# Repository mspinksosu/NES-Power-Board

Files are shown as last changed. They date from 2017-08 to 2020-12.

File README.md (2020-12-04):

# NES-Power-Board
A PCB that will fit in place of the stock NES frontloader's RF module.
***
This PCB will replace the stock RF modulator box. It will have different connector options for outputting audio and video, as well as a breakout for the channel select switch.

I plan to support:
* composite video with mono audio
* composite video and "stereo" audio (standard 3 RCA TV connection)
* RGB + composite using a Retrofixes SNES style multiout connector.  (Requires existing RGB mod) This will be my version.
* RGB output directly to the Framemeister's 8-pin mini DIN connector. (Requires existing RGB mod)

The first two options require no modification to the chassis. All other versions will require some chassis modification, but it will minimal.

This PCB is designed specifically with Tim Worthington's NESRGB board in mind. The channel select switch will have a breakout so that it can be used as a palette selector switch.
***
# To-Do List for Rev 3
- [x] Flip ribbon connector. It will make the ribbon lay flatter (already did this for rev 2 doh!)
- [x] Check all through holes before sending to board house!
- [x] Change routing of RGB traces and audio traces completely
- [x] Separate video signals from audio signals to help avoid the static issue with the noise channel (may try 4 layer)
- [ ] Fix mounting hole location (may need to move J2)
- [x] C4 and C6 collide with heatsink of U1
- [x] Move components to bottom (working from the top is more difficult after installed)
- [x] Add extra surface mount ribbon connector, 1.27 mm pitch
- [ ] Test composite output (check if transistor bandwidth is sufficient)
- [ ] Band pass filter?

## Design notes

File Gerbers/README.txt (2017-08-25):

Project: NES Power PCB

Engineer: Matthew Spinks
Work Phone:
Evening Phone:

Address:

********************************************************************************

Unit = Inches
Format = 2:4
Filetype = 274X

Dimensions:
X = 2.738"
Y = 2.866"

Layer Count = 2
Thickness = 0.062"
Copper Wt. = 1 oz
Silkscreen: Both Sides

Files:

.DRL    Binary Drill File
.GBL    Bottom Copper
.GBO    Bottom Silkscreen
.GBS    Bottom Soldermask
.GD1    Drill Drawing
.GG1    Drill Guide
.GM1	Board Outline
.GTL    Top Copper
.GTO    Top Silkscreen
.GTS    Top Soldermask
.TXT    NC Drill File

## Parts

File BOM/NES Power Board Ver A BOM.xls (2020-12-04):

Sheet: Part List Report
 |  | Bill of Materials |  | NES Power Board Ver A.PrjPcb |  | Revision | 2000-02-05
 |  | Project: |  | NES Power Board Ver A.PrjPcb
 |  | Engineer:
 |  | Report Date: | 2020-12-03 | 20:12:00
 |  | Print Date: | 2020-12-03 | 20:12:32
# | Quantity | Value | Designator | Footprint | Description | Manufacturer 1 | Manufacturer Part Number 1 | Supplier 1 | Supplier Part Number 1
1 | 6 |  | Audio_L, Audio_R, GND, RCA_A, RCA_V, Video | WIREPAD-09-15 | Wire Pad, 1 Pin, Through Hole, Vertical
2 | 1 | 2200uF | C1 | TH CAP-12.5X25MM-A1K2 | CAP, ALUM, TH, 12.5x25mm, 2200uF, 25V, 20%, Pitch 5.0mm | Panasonic | ECA-1EHG222 | Mouser | 667-ECA-1EHG222
3 | 3 | 10nF | C2, C4, C5 | CAP 0805_N | CAP, CER, 0805, 10nF, 50V, X7R, 10%
4 | 1 | 100uF | C3 | TH CAP-6.3X11MM-A1K2 | CAP, ALUM, TH, 6.3x11mm, 100uF, 25V, 20%, Pitch 2.5mm | Panasonic | ECA-1EM101 | Mouser | 667-ECA-1EM101
5 | 1 | 0.1uF | C6 | CAP 0805_N | CAP, CER, 0805, 0.1uF, 50V, X7R, 10%
6 | 2 | 10uF | C7, C8 | CAP EIA-A (3216) A1K2 | CAP, TANT, 1206, 10uF, 16V, 10% | Kyocera AVX | TAJA106K016RNJ | Mouser | 581-TAJA106K016R
7 | 1 | DF206-ST | D1 | DFS4 | Full Wave Diode Bridge | Comchip | DF206ST-G | Mouser | 750-DF206ST-G
8 | 1 | PJ-037A | J1 | PWR-JCK-ALT (PJ-037A/B) | 2.1mm ID, DC Power Supply Connector, 2 Pin | CUI Devices | PJ-037A | Mouser | 490-PJ-037A
9 | 1 | RF Board Connector | J2 | RF Board Connector | Motherboard Connector to RF/Power Module
10 | 1 | 1.27mm Pitch | J3 | HDR1x11-15MM VERTL - L | Video and audio inputs for the RF Board Mod
11 | 1 | 1.27mm Pitch | J3A | SMD1x11-127MM | Video and audio inputs for the RF Board Mod
12 | 1 | Header 1x4 1.27mm | J4 | HDR1X4-15MM VERT - L | Header, 4 Pin, 1.5mm Pitch, Vertical
13 | 1 | MD-80SM | J5 | MINI-DIN-8-ALT (MD-80SM) | 8 Pin Mini DIN Connector, Shielded, Through Hole, Right Angle | CUI Devices | MD-80SM | Mouser | 490-MD-80SM
14 | 1 | Multiout | J6 | Multiout-2 | SNES Multiout Connector
15 | 2 | RCJ-042 | J7, J8 | RCA-JCK-1 (RCJ-042-ALT1) | RCA Phono Jack, Right Angle | CUI Devices | RCJ-042 | Mouser | 490-RCJ-042
16 | 1 | BC817 | Q1 | SOT23-3 | General Purpose Transistor, NPN, 3-Pin, B1E2C3 | ON Semiconductor | BC817-40LT1G | Mouser | 863-BC817-40LT1G
17 | 2 | 330 | R1, R3 | RES 0805_N | RES, SMD
18 | 1 | 5.6k | R2 | RES 0805_N | RES, SMD
19 | 1 | 560 | R4 | RES 0805_N | RES, SMD
20 | 1 | 75 | R5 | RES 0805_N | RES, SMD
21 | 2 | NA | RJA-EXT, RJV-EXT | RES 0805_N | RES, SMD
22 | 3 | 0 | RJA-INT, RJV-INT, RMONO | RES 0805_N | RES, SMD
23 | 1 | 470 | RSYNC | RES 0805_N | RES, SMD
24 | 1 | EG2319 | SW1 | SW-DP3T (EG2319) | Dual Pole, Three Throw | E-Switch | EG2319 | Mouser | 612-EG2319
25 | 1 | L7805ABD2T | U1 | D2PAK (TO-263) | Fixed 5V Regulator, 1.5A, D2PAK | STMicroelectronics | L7805ABD2T-TR | Mouser | 511-L7805ABD2T-TR
Notes

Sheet: Project Information
Project Full Path | C:\Users\maspin\Documents\GitHub\NES-Power-Board\NES Power Board Ver A.PrjPcb
Project Filename | NES Power Board Ver A.PrjPcb
Variant Name | None
Data-Source Filename | NES Power Board Ver A.PrjPcb
Data-Source Full Path | C:\Users\maspin\Documents\GitHub\NES-Power-Board\NES Power Board Ver A.PrjPcb
Title | NES Power Board Ver A.PrjPcb
Total Quantity | 38
Report Time | 20:12:00
Report Date | 2020-12-03
Report Date & Tine | 2020-12-03 20:12
Output Name | Bill of Materials
Output Type | BOM_PartType
Output Generator Name | BOM
Output Generator Description | Bill of Materials

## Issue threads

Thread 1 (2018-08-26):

Cannot Import Power PCB.PcbDoc in Altium CircuitStudio File Corrupt

R5D4ca, 2018-08-26:
Hello,
I'm interested in the project and new to PCB design in general, I wanted to try and open the design files and poke around but it looks like your files are from Altium Designer (based on the file extension and embedded metadata) and I only have a trial version of CircuitStudio available to me.  When I tried to import the necessary files the schematic file came in no problem but the PCB file says it is corrupt.

So far as I can tell so long as the PCB file from Altium Designer is version 5.0 or 6.0 this import should work.
Was wondering if you might know how to address this please?

mspinksosu, 2018-08-26:
Not sure about this one. I'll have to look into it tomorrow. I've left my
laptop at work which has Altium on it. Did you mean to say Altium 15.0 or
16.0? I know Altium has some built in exporters now, but I don't think they
go back that far.

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

R5D4ca, 2018-08-26:
Thanks for the response, you know strangely enough it only offers Altium PCB 5.0 and 6.0 as an option for importing.

Googling about this issue brought up a youtube video [https://www.youtube.com/watch?v=YAWBsShCId4](url) where the guy essentially says Altium seems to be purposely limiting the import abilities to older versions to remove overlap between the two products (great - love when companies do that).  Fortunately he also says you can simply re-save the PCB file to a version 5.0 from within Altium Designer to get around this issue and that the new file should just work.

R5D4ca, 2019-01-12:
I thought I had mentioned it here but I guess not; the reason I was trying to load the files is because when I go to OSH Park to try and print the PCB it gave me an error with the drill file but since you've upload the new version I've tried it again and now it gives me errors with the copper layer, mask layer, outline file, and drill file lol

Any chance for assistance please?  :)

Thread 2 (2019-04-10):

Incorrect Part Number

bikedude880, 2019-04-10:
https://github.com/mspinksosu/NES-Power-Board/blob/e8f472a10f18f6f2d27275b2264882e76d683c5a/NES%20Power%20Board.Dat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

This pad calls for a SPDT slide switch. This should really be a DP3T switch given the landing for the part.

Which manufacturer part is this now? Current one is SPDT and will never fit.

bikedude880, 2019-04-10:
Following part seems to be a fit for the landing:

E-Switch EG2319

https://www.mouser.com/ProductDetail/E-Switch/EG2319?qs=f57gQzlyLirXT6sCFZHxDA%3D%3D

bikedude880, 2019-04-11:
Please also note that R1, R2 and R3 are also missing.

radabass, 2019-07-10:
Hi @bikedude880, the part is the EG2322

https://eu.mouser.com/ProductDetail/E-Switch/EG2322?qs=sGAEpiMZZMvGqlubrpfvZYMIW9vnpXDI

As you can see in the commit https://github.com/mspinksosu/NES-Power-Board/commit/bfbaa42909d37d6ba6428c98cd207ca6bb8a1903

mspinksosu, 2020-12-04:
BOM has been added for version 2-5-0 (version A).

Closed 2020-12-04.

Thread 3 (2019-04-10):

Not all connectors plated through

bikedude880, 2019-04-10:
Not plated:
J2 - Motherboard Connector
J4 - Switch Breakout
J6 - Retrofixes MultiOut Connector

icestormmusic, 2019-05-20:
@bikedude880 - I am looking at doing this upgrade as well.  Did you have to modify the board before getting it printed to correct this issue?  I'm not much of a circuit guy, but I can solder.

bikedude880, 2019-06-01:
@icestormmusic I only noticed after printing the board, so yes. For J2, I took 24 gauge stranded wire, splayed it out and soldered it one side, pulled it through and soldered the other. SW1 can have patch wire run from the bottom of connector, non-issue.
J6 is where things get interesting. All the signal connections are made in the top of the board underneath the physical connector. This needs to be fixed in the Gerber files.

Also note that there is an issue using the stock composite circuit out from J2. The circuit is missing a band-pass filter after R5 which requires a 3.3mH inductor and capacitor. Without this the only thing this board is good for currently is power :(

OOF1337, 2020-12-01:
I know this is an old thread but are there any other issues with it? I'm thinking of hiring someone to fix the issues if there are any.

mspinksosu, 2020-12-01:
There are issues with it. It's noisy. When I originally made it, I had designed it in such a way that it could be made at home if desired. That means that I intentionally tried to use a small number of vias. Some of the traces snake around pins on the RGB connector. It's now so cheap to get a board from a fab house that this no longer necessary. I'll remake it someday with a 4 layer board when I'm not busy and COVID-19 is over with

OOF1337, 2020-12-01:
Hi! While I have you here this is about the revision 2.0A and B correct? How identical are they from one another? From what I can tell version B doesn't support RGB while A does but other than those differences, as the layout and schematics model currently stand, would there be any other advantages in going with one or the other?

bigboy061293, 2020-12-02:
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

I guess the non plated issues were fixed in the lasted revision. We just need to add the BPF, right?

OOF1337, 2020-12-02:
@bigboy061293 Did you check the 2.0 file A or B directly to see if the plated issues were fixed? If so, do you know where to put the Vias or Band-pass filter? can you also tell me what "J6 is where things get interesting. All the signal connections are made in the top of the board underneath the physical connector." means? Sorry for being nosey XD.

mspinksosu, 2020-12-02:
2.0 A and B should have fixed the through hole plating, but I'll have to check when I get home. Currently working at night due to covidiots at work. 1.0 was my first time using Altium and I goofed. I've also had some issues syncing Github between home computer and work computer. Next time, I'll just get a portable drive.

mspinksosu, 2020-12-02:
I

> Hi! While I have you here this is about the revision 2.0A and B correct? How identical are they from one another? From what I can tell version B doesn't support RGB while A does but other than those differences, as the layout and schematics model currently stand, would there be any other advantages in going with one or the other? Thank you for your previous response by the way, wasn't expecting that!

I originally tried to make one board with two connectors. I literally just tried to place the two footprints on top of each other, but they way the holes are I had to push the mini din connector back into the housing and I didn't like that. So on the next revision, I made two different versions. I believe every thing else is the same. But again, I'll have to check

OOF1337, 2020-12-02:
@mspinksosu Once again, thank you for the reply.

mspinksosu, 2020-12-02:
> Also note that there is an issue using the stock composite circuit out from J2. The circuit is missing a band-pass filter after R5 which requires a 3.3mH inductor and capacitor. Without this the only thing this board is good for currently is power :(

I did find a somewhat crudely drawn, reverse engineered schematic for the RF box and I saw the filter. I did a limited amount of research into the composite output. I mostly looked at mods that were applied to the NES top loader to add composite output. It would appear that most top loader mods just consist of a single transistors and a few resistors and caps. I assumed that the filter was there to limit noise from the RF modulator literally inches away. And since I am removing the RF modulator entirely, I just assume that I don't need it. I have not had a chance to test it

bigboy061293, 2020-12-02:
> > Also note that there is an issue using the stock composite circuit out from J2. The circuit is missing a band-pass filter after R5 which requires a 3.3mH inductor and capacitor. Without this the only thing this board is good for currently is power :(
>
> I did find a somewhat crudely drawn, reverse engineered schematic for the RF box and I do remember seeing a filter in there. (I can't remember exactly what values) I did a limited amount of research into the composite output. I mostly looked at mods that were applied to the NES top loader to add composite output. It would appear that most top loader mods just consist of a single transistors and a few resistors and caps. I assumed that the filter was there to limit noise from the RF modulator literally inches away. And since I am removing the RF modulator entirely, I just assume that I don't need it. I have not had a chance to test it

I guess we need to look at the frequency characteristic of Video Out (Which I have not researched yet) and could replicated the BPF.

mspinksosu, 2020-12-04:
> I know this is an old thread but are there any other issues with it? I'm thinking of hiring someone to fix the issues if there are any.

I took a little, much needed time off and did up a version 2-5-0 for you. All plated holes are fixed and I re-routed a majority of the traces to try to improve noise issues. I'm only doing the version with the mini-din connector for now (version A). I'll do the other one after I've tested the first. I don't want to waste money on two PCB's unless I know it's going to work.

Unfortunately, I'm not sure when I'll be able to actually test it out. I've got a lot of mandatory home renovation going on (2020 is literally the worst). But I can order 10 PCB's and if you give me a few bucks, I can ship you one flat rate.

Once everything is done, I'll update Hackaday again.

OOF1337, 2020-12-06:
@mspinksosu While I appreciate the offer there are things I have to wait on first before I could definitively say yes or no. I'll let you know when I can give you an answer. I do appreciate your work on this though! My goal was to contribute towards the goal of making sure that there are open source solutions for the NES ever since the Opentendo was created earlier this year and I thought that aside from a 3d printed case model and controller ports that the RF/power adapter was the last piece in the puzzle for a open source NES.

SteelBattalion, 2021-04-24:
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

I know this is an old thread but do you still have any of those extra boards?

mspinksosu, 2021-04-24:
> I know this is an old thread but do you still have any of those extra boards?

Hi. So I actually left my old job and got a new one a few states away. Things have been pretty crazy. I'm still in the process of selling and buying a house, so everything I own is in storage right now. Not sure when I'll be able to get them. My goal is to move into a new house by the end of this summer.

zombie343, 2022-03-13:
Hi @mspinksosu, I hope your move went well. 👍  I've been following this project because I'd like to replace the RF box on my front-loader and mix the stereo output. :)

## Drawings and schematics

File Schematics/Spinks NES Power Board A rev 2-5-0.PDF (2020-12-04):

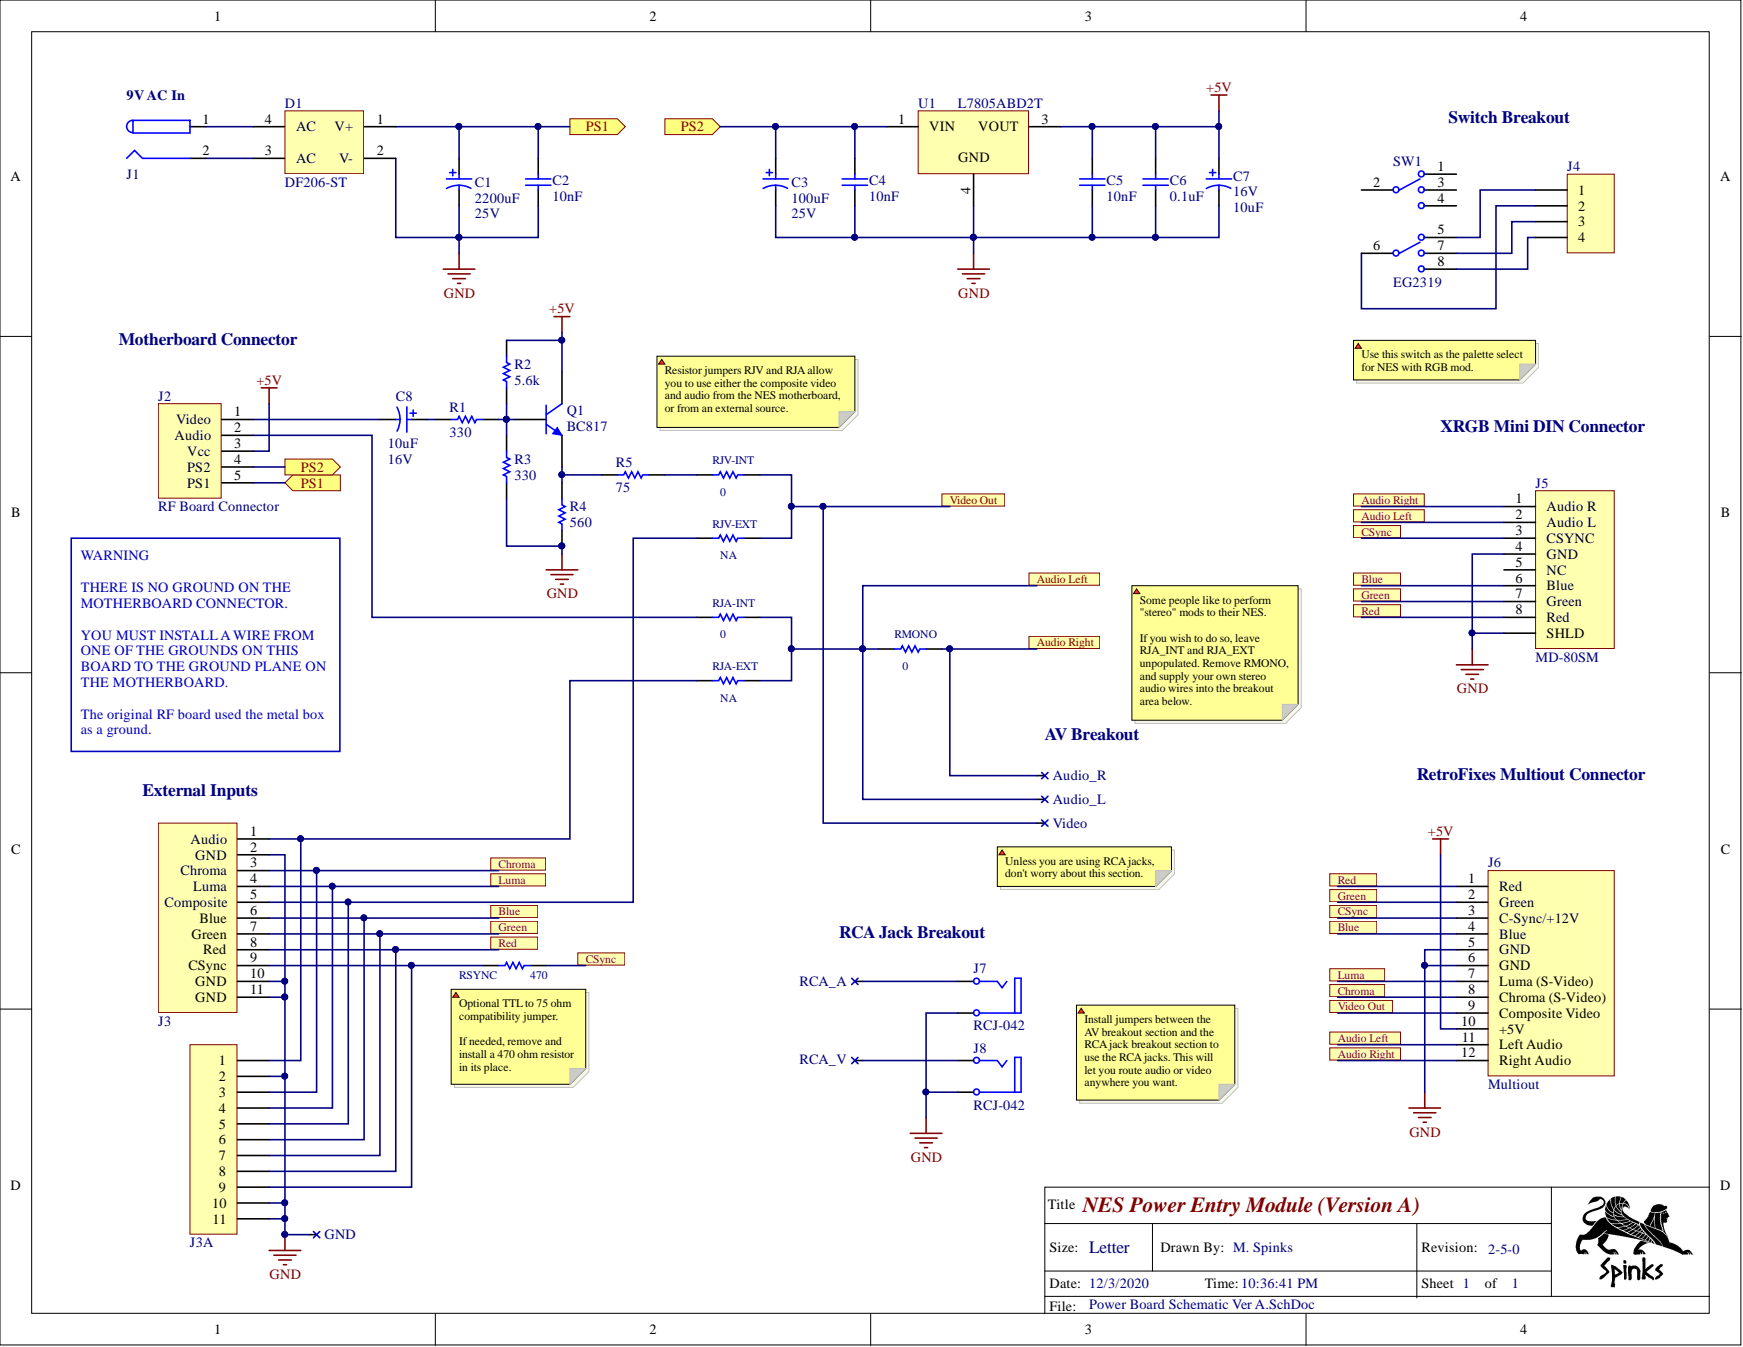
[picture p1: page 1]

Use this switch as the palette select
for NES with RGB mod.

Resistor jumpers RJV and RJAallow
you to use either the composite video
and audio from the NES motherboard,
or from an external source.

XRGB Mini DIN Connector

Audio Left | Audio L 2
CSync | CSYNC 3

GND 4
NC 5

THERE IS NO GROUND ON THE
MOTHERBOARD CONNECTOR.

Green | | Green 7
Red | | Red 8

Some people like to perform
"stereo" mods to their NES.

YOU MUST INSTALL A WIRE FROM
ONE OF THE GROUNDS ON THIS
BOARD TO THE GROUND PLANE ON
THE MOTHERBOARD.

If you wish to do so, leave
RJA_INT and RJA_EXT
unpopulated. Remove RMONO,
and supply your own stereo
audio wires into the breakout
area below.

The original RF board used the metal box
as a ground.

Unless you are using RCAjacks,
don't worry about this section.

Chroma | | Chroma (S-Video) 8
Video Out | | Composite Video 9

Optional TTL to 75 ohm
compatibility jumper.

Install jumpers between the
AV breakout section and the
RCAjack breakout section to
use the RCAjacks. This will
let you route audio or video
anywhere you want.

If needed, remove and
install a 470 ohm resistor
in its place.

NES Power Entry Module (Version A) Title

Size: Letter | Drawn By: M. Spinks | Revision: 2-5-0

Date: 12/3/2020 Time: 10:36:41 PM | | Sheet 1 of 1

Power Board Schematic Ver A.SchDoc
File:

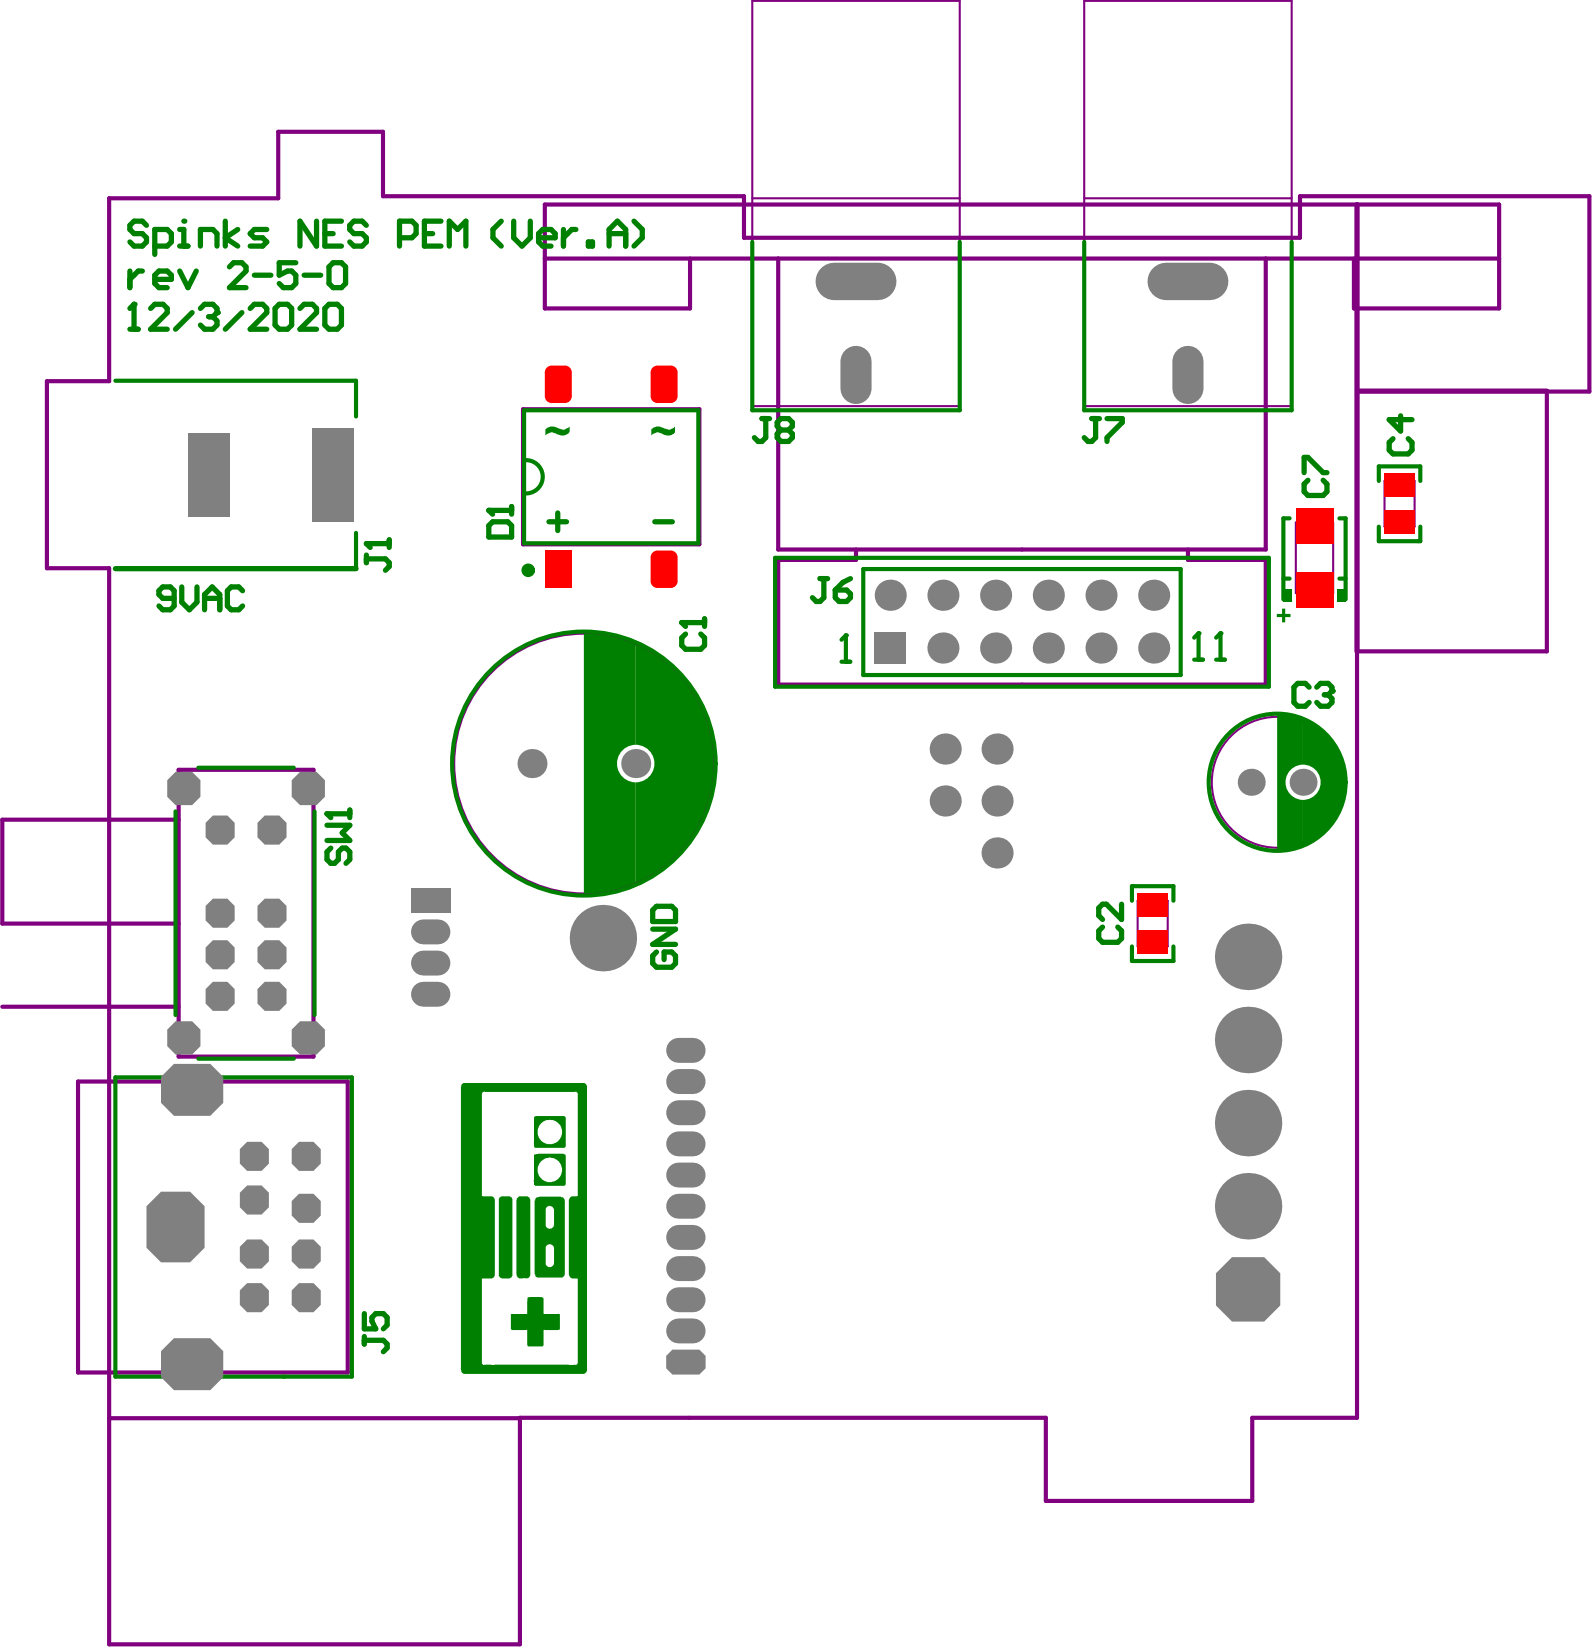
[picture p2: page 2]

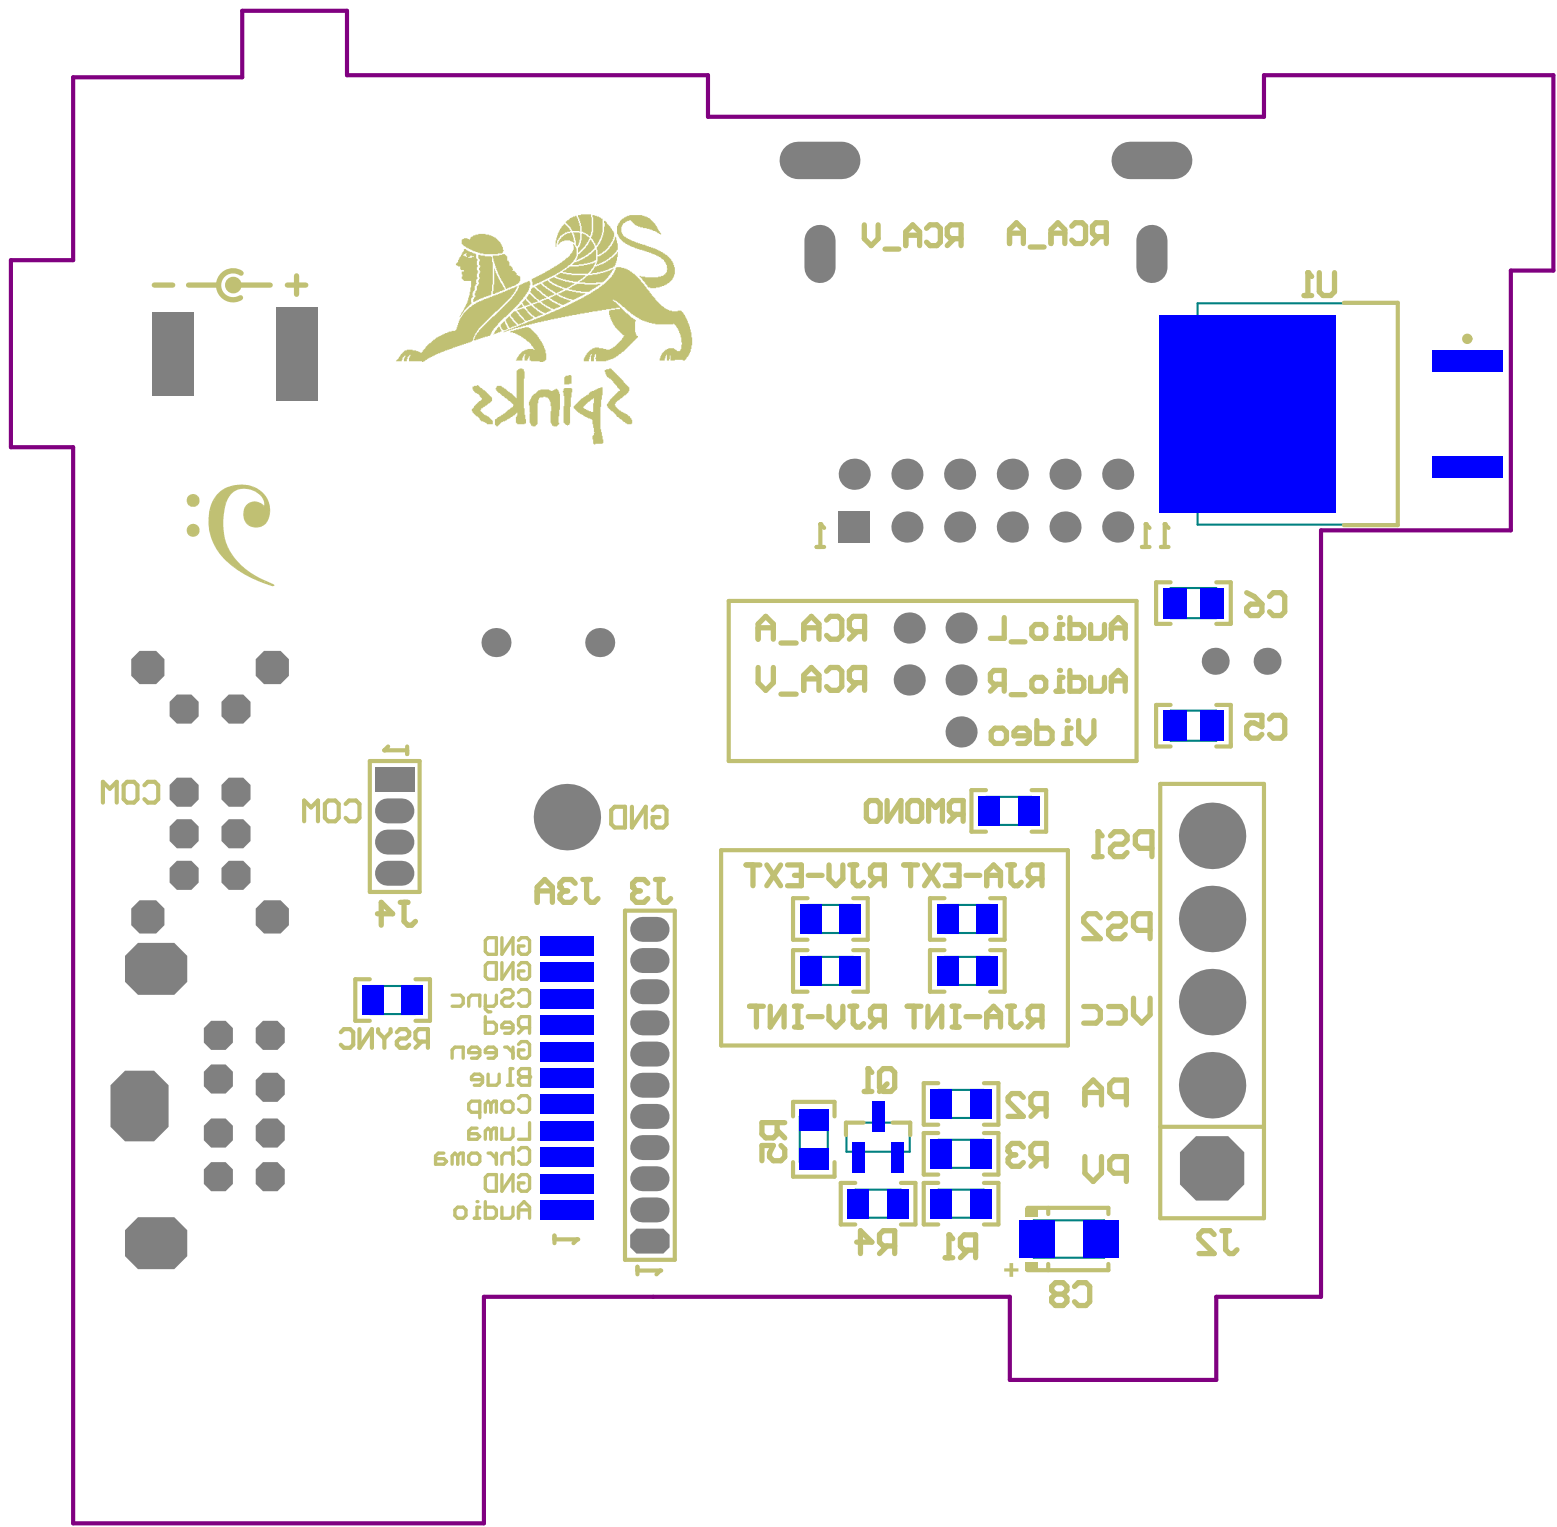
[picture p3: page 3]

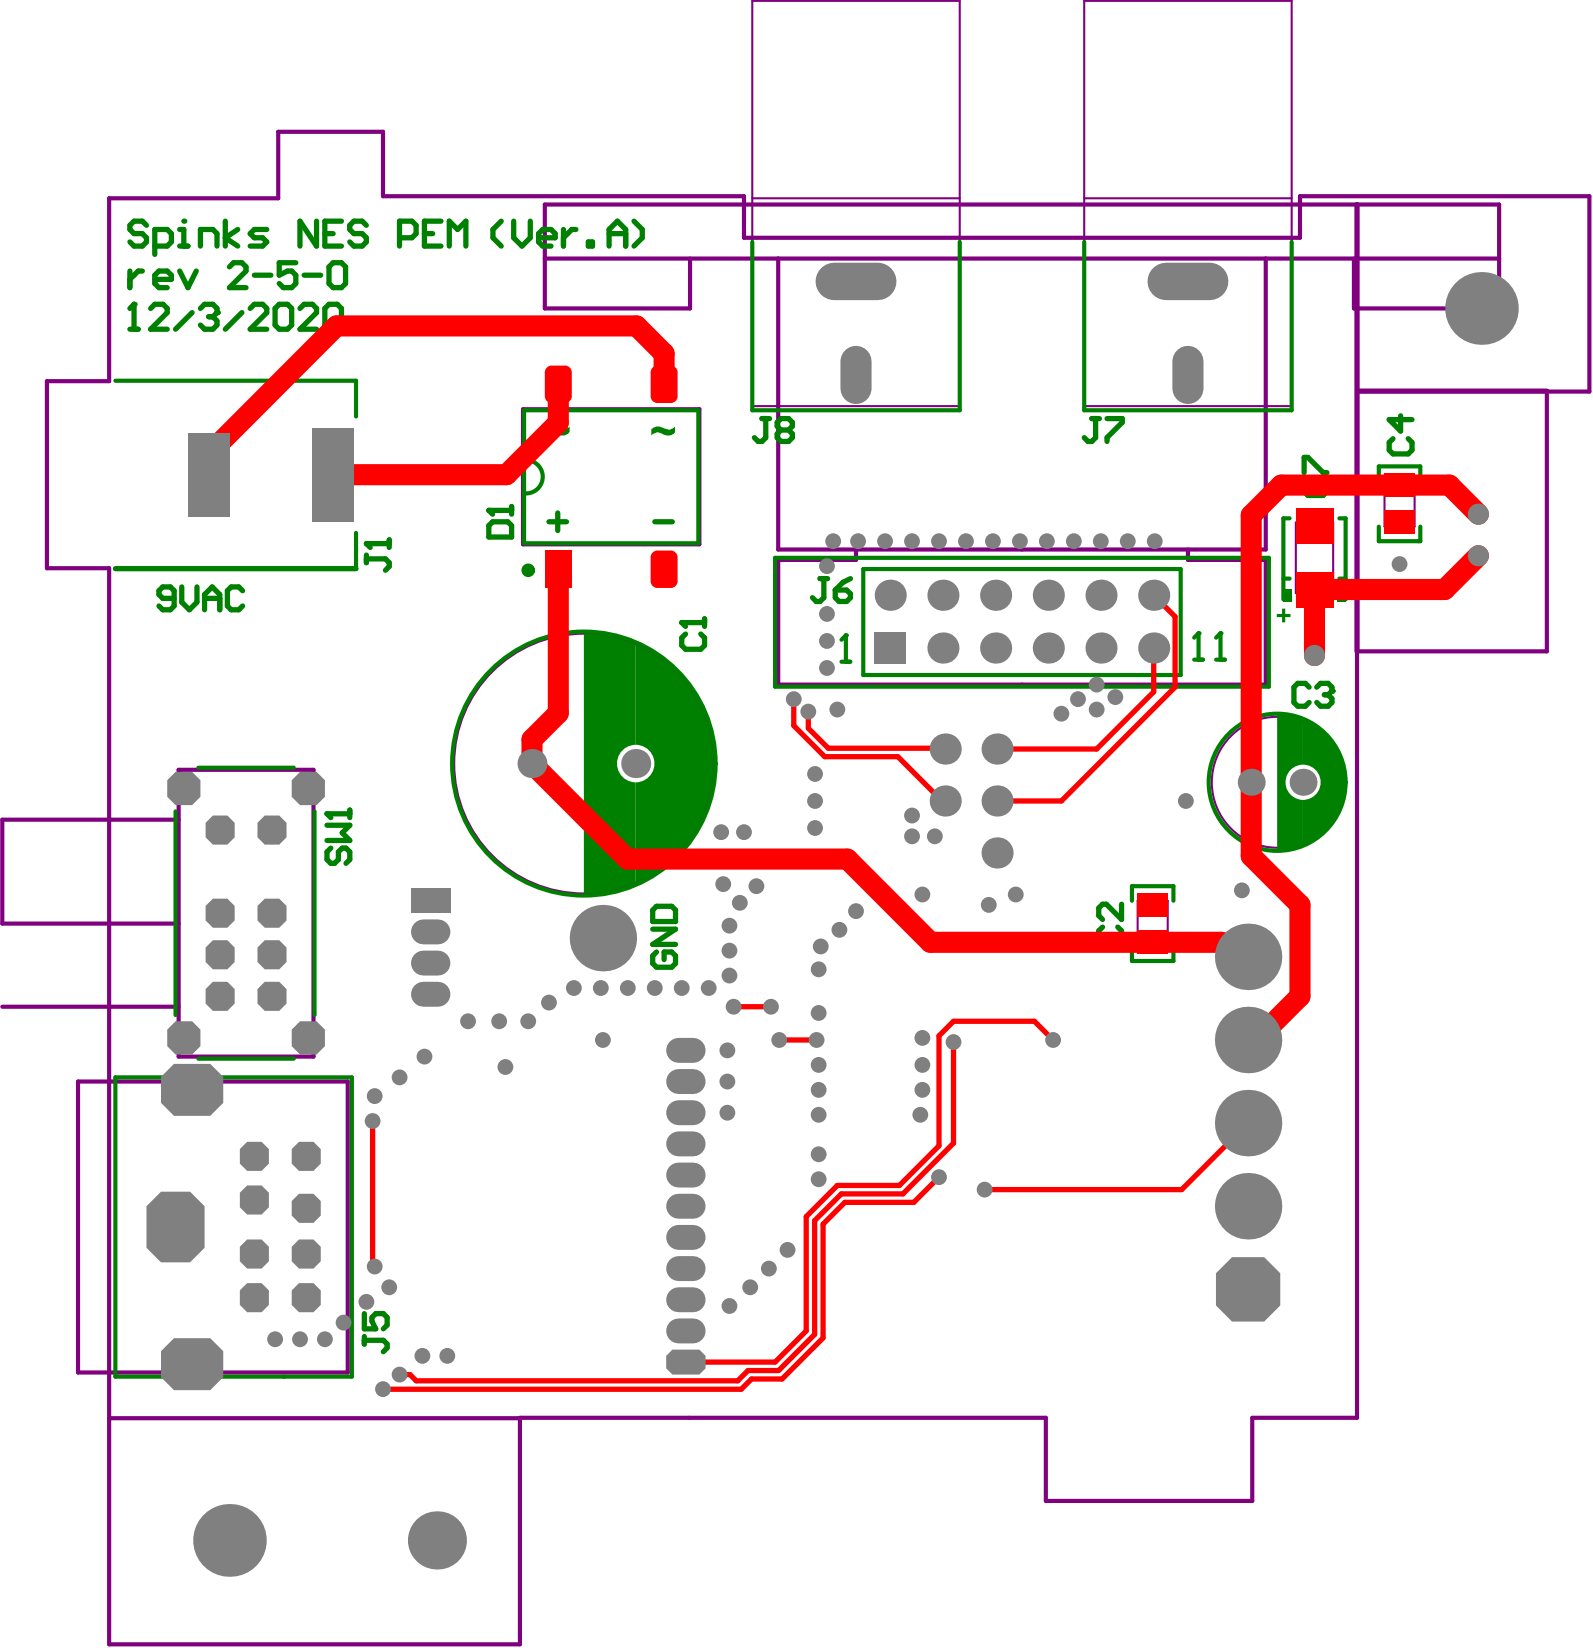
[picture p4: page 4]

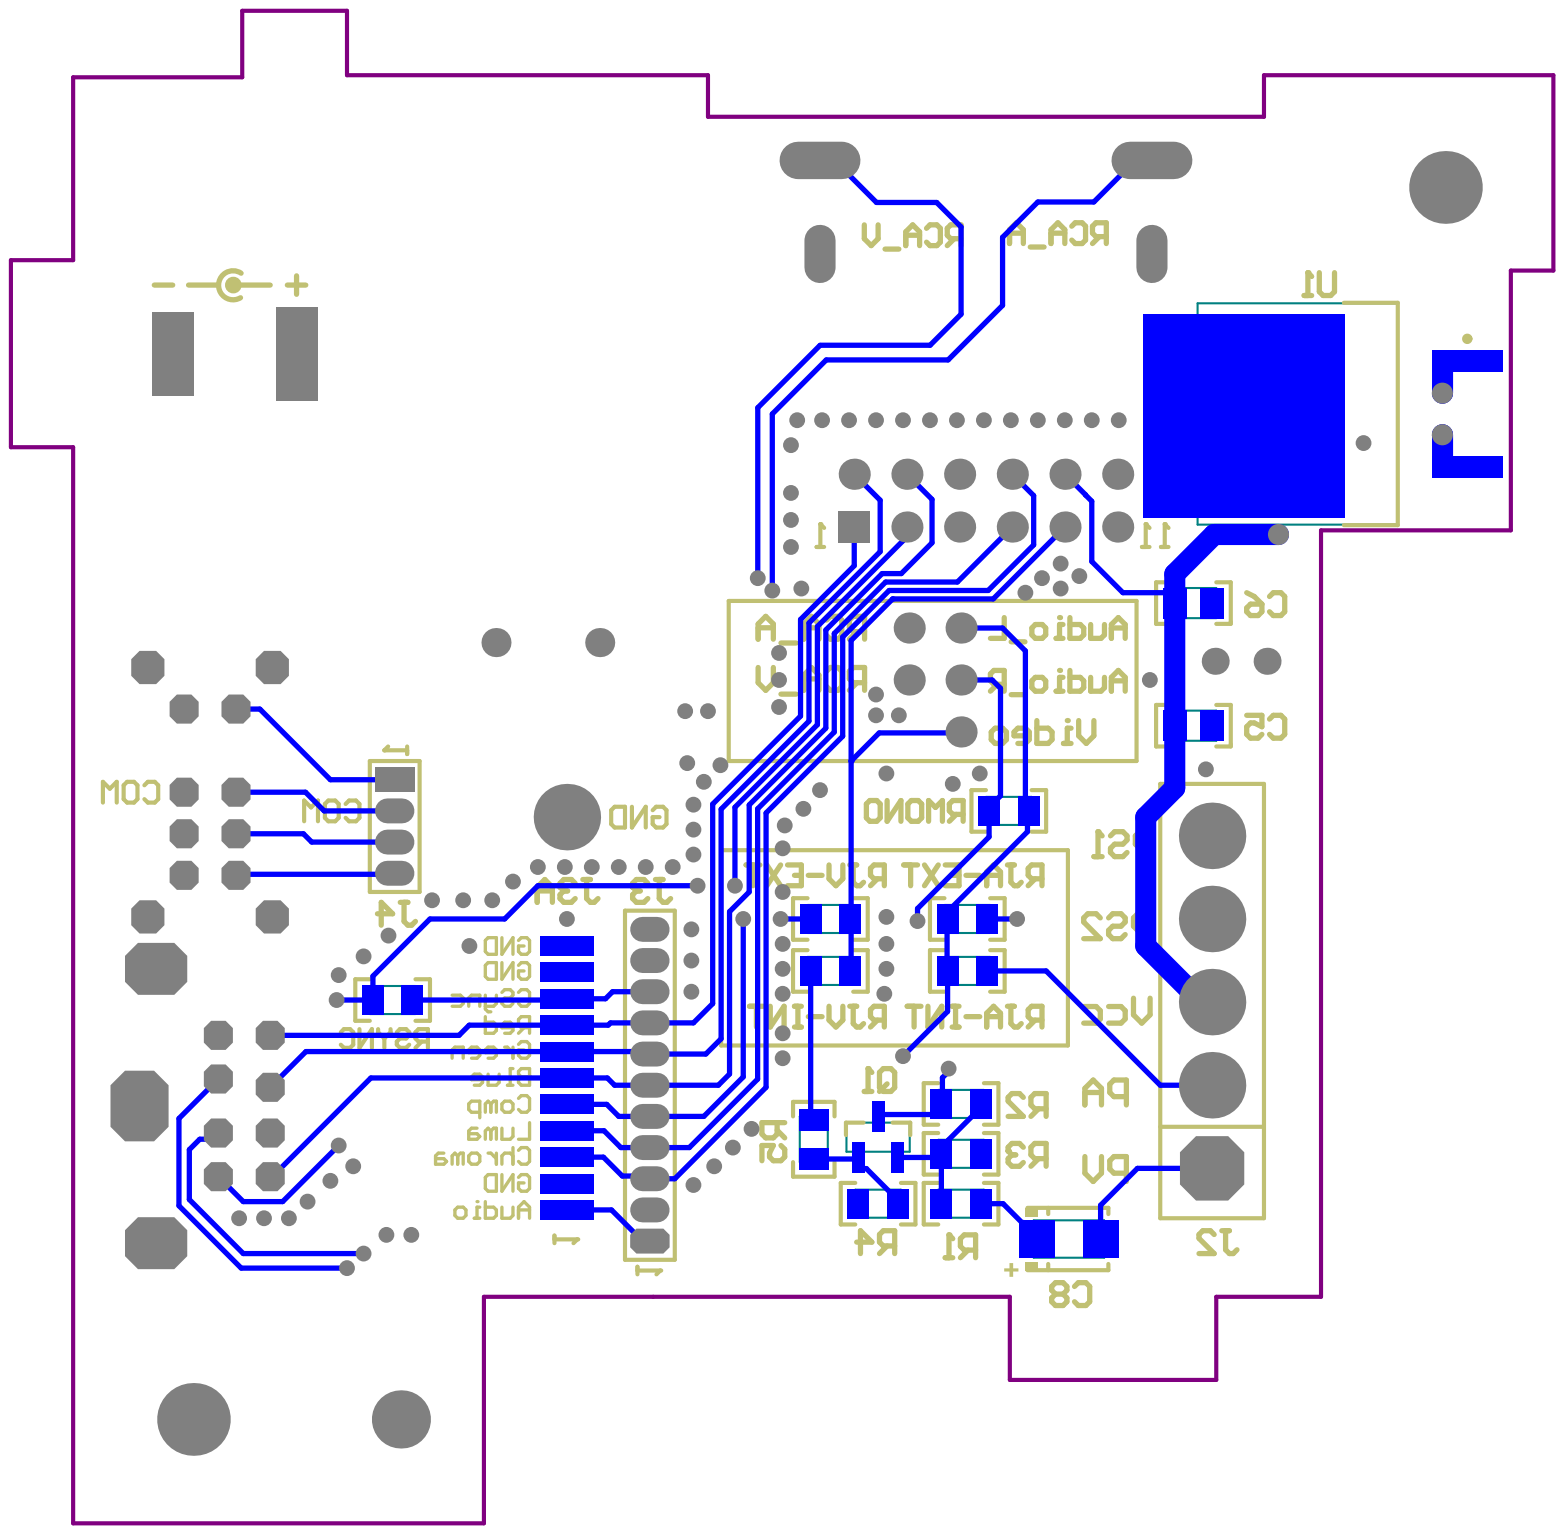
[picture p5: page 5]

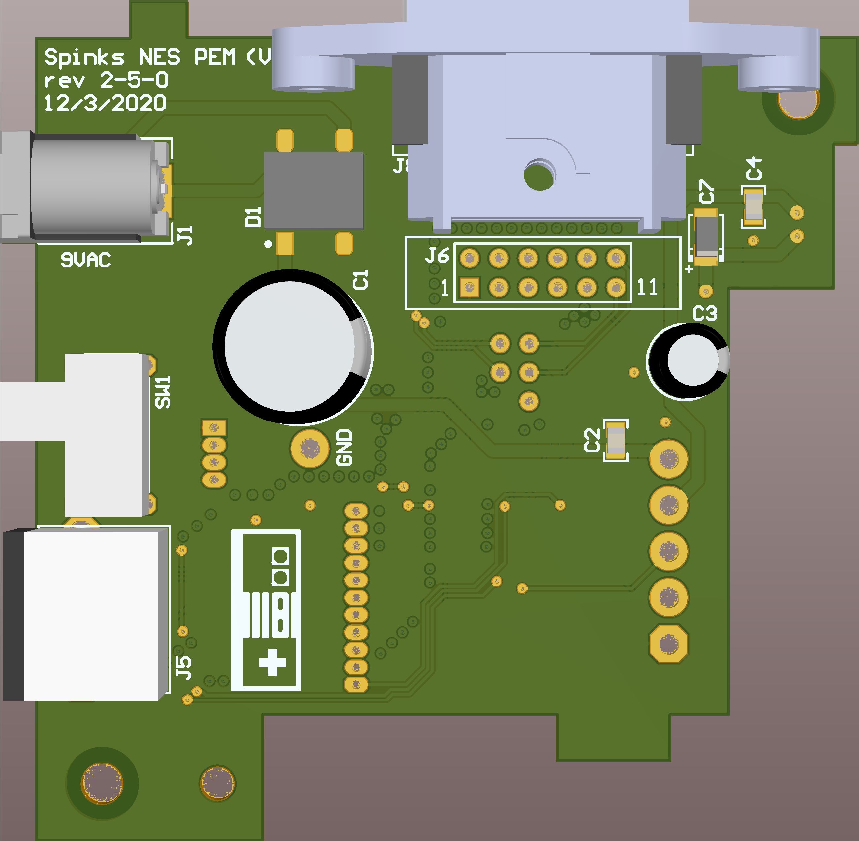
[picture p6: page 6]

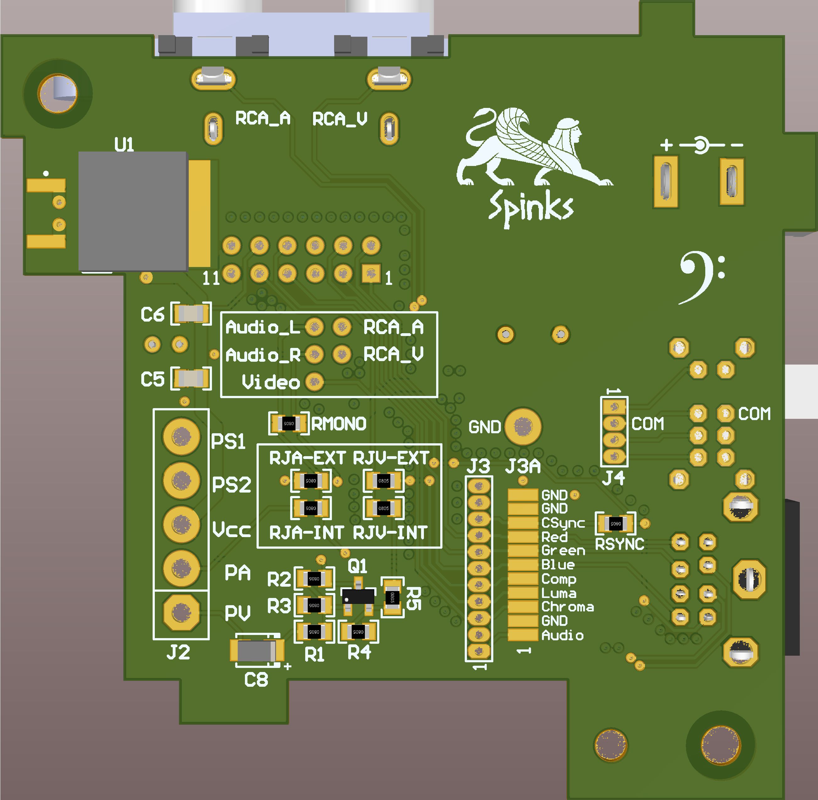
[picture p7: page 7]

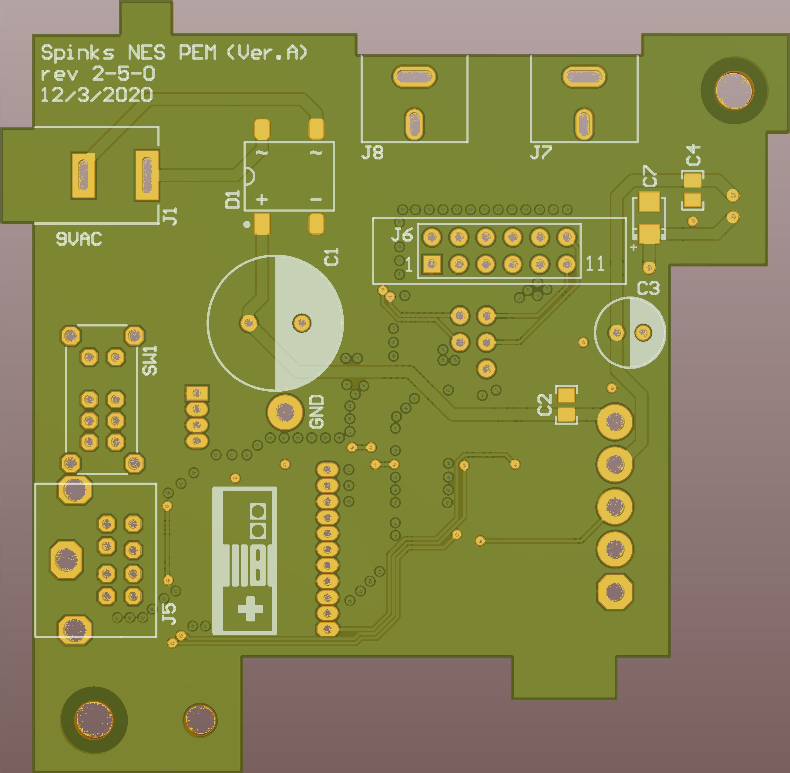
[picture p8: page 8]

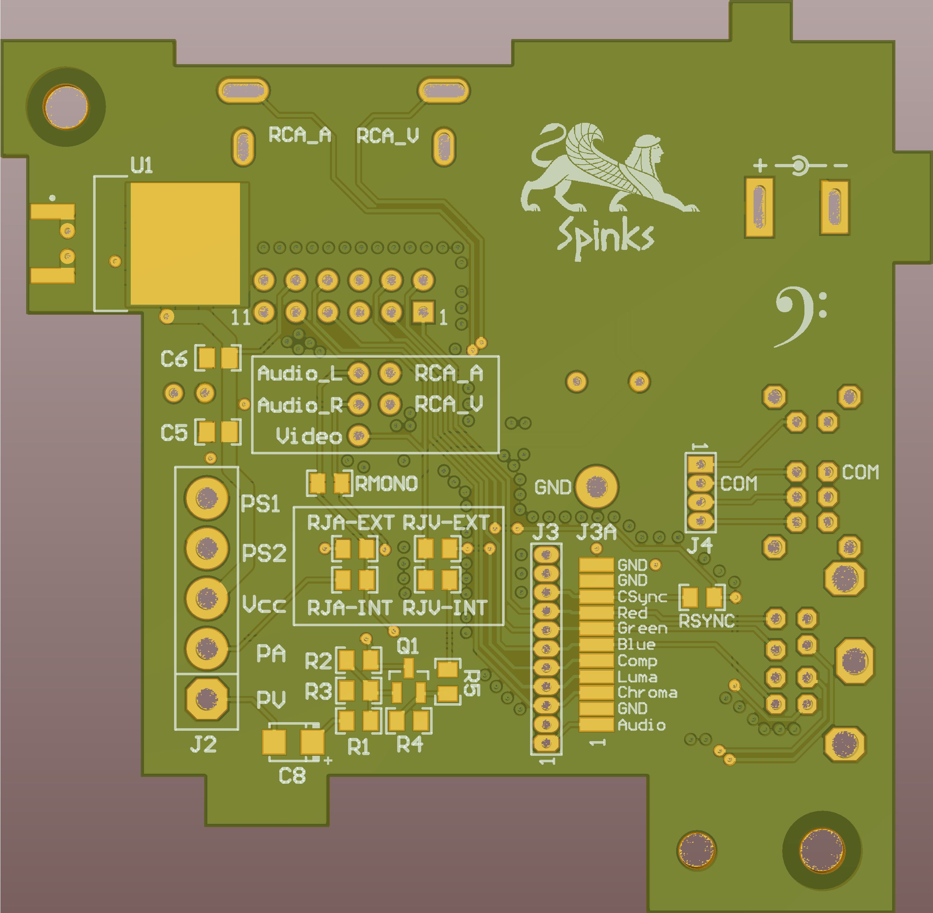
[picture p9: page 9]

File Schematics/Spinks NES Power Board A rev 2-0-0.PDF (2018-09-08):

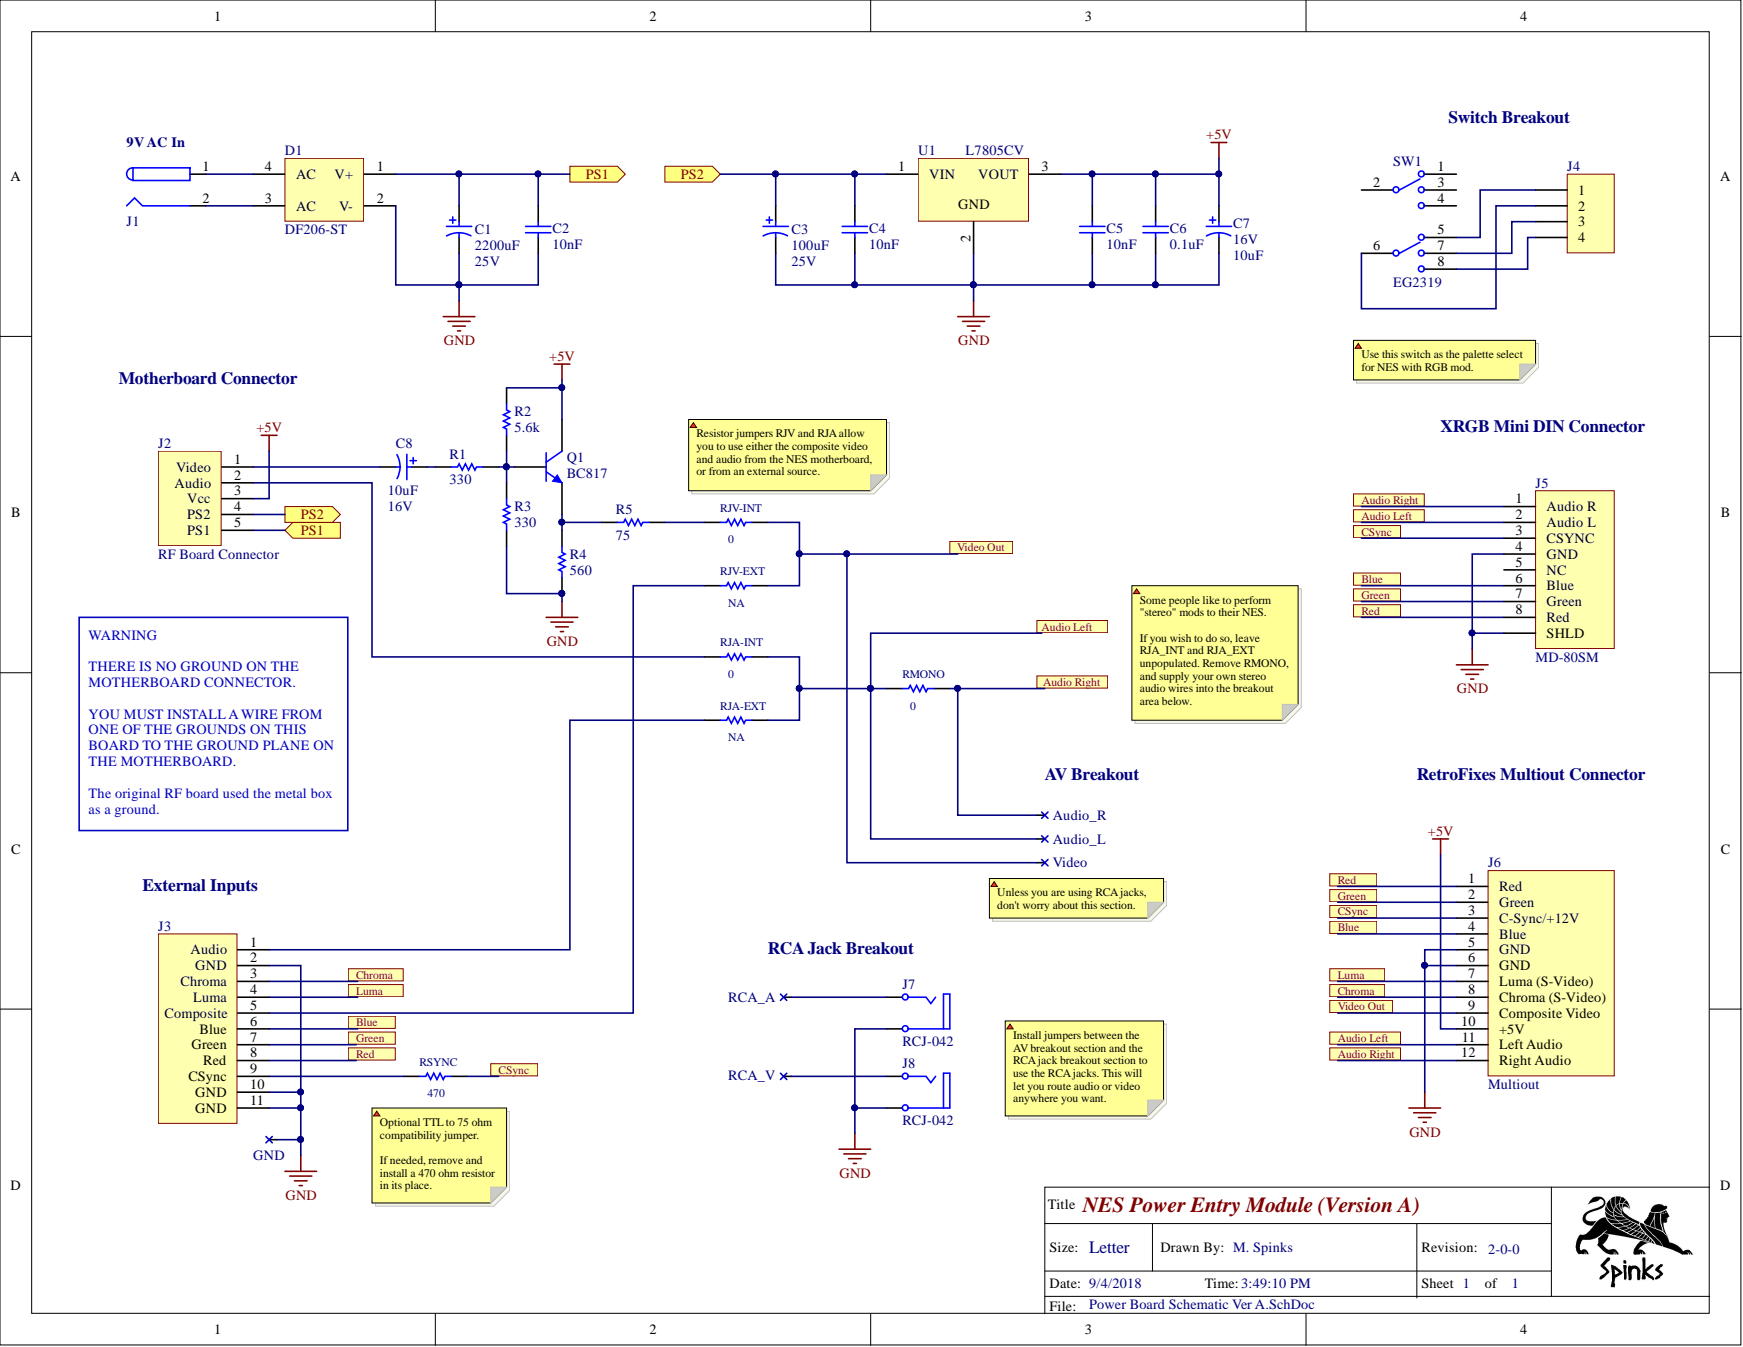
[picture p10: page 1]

Use this switch as the palette select
for NES with RGB mod.

Resistor jumpers RJV and RJAallow
you to use either the composite video
and audio from the NES motherboard,
or from an external source.

XRGB Mini DIN Connector

Audio Left | Audio L 2
CSync | CSYNC 3

Green | | Green 7
Red | | Red 8

Some people like to perform
"stereo" mods to their NES.

If you wish to do so, leave
RJA_INT and RJA_EXT
unpopulated. Remove RMONO,
and supply your own stereo
audio wires into the breakout
area below.

THERE IS NO GROUND ON THE
MOTHERBOARD CONNECTOR.

YOU MUST INSTALL A WIRE FROM
ONE OF THE GROUNDS ON THIS
BOARD TO THE GROUND PLANE ON
THE MOTHERBOARD.

The original RF board used the metal box
as a ground.

Unless you are using RCAjacks,
don't worry about this section.

Green | Green 2
CSync | C-Sync/+12V 3
Blue | Blue 4

Install jumpers between the
AV breakout section and the
RCAjack breakout section to
use the RCAjacks. This will
let you route audio or video
anywhere you want.

Optional TTL to 75 ohm
compatibility jumper.

If needed, remove and
install a 470 ohm resistor
in its place.

NES Power Entry Module (Version A) Title

Size: Letter | Drawn By: M. Spinks | Revision: 2-0-0

Date: 9/4/2018 Time: 3:49:10 PM | | Sheet 1 of 1

Power Board Schematic Ver A.SchDoc
File:

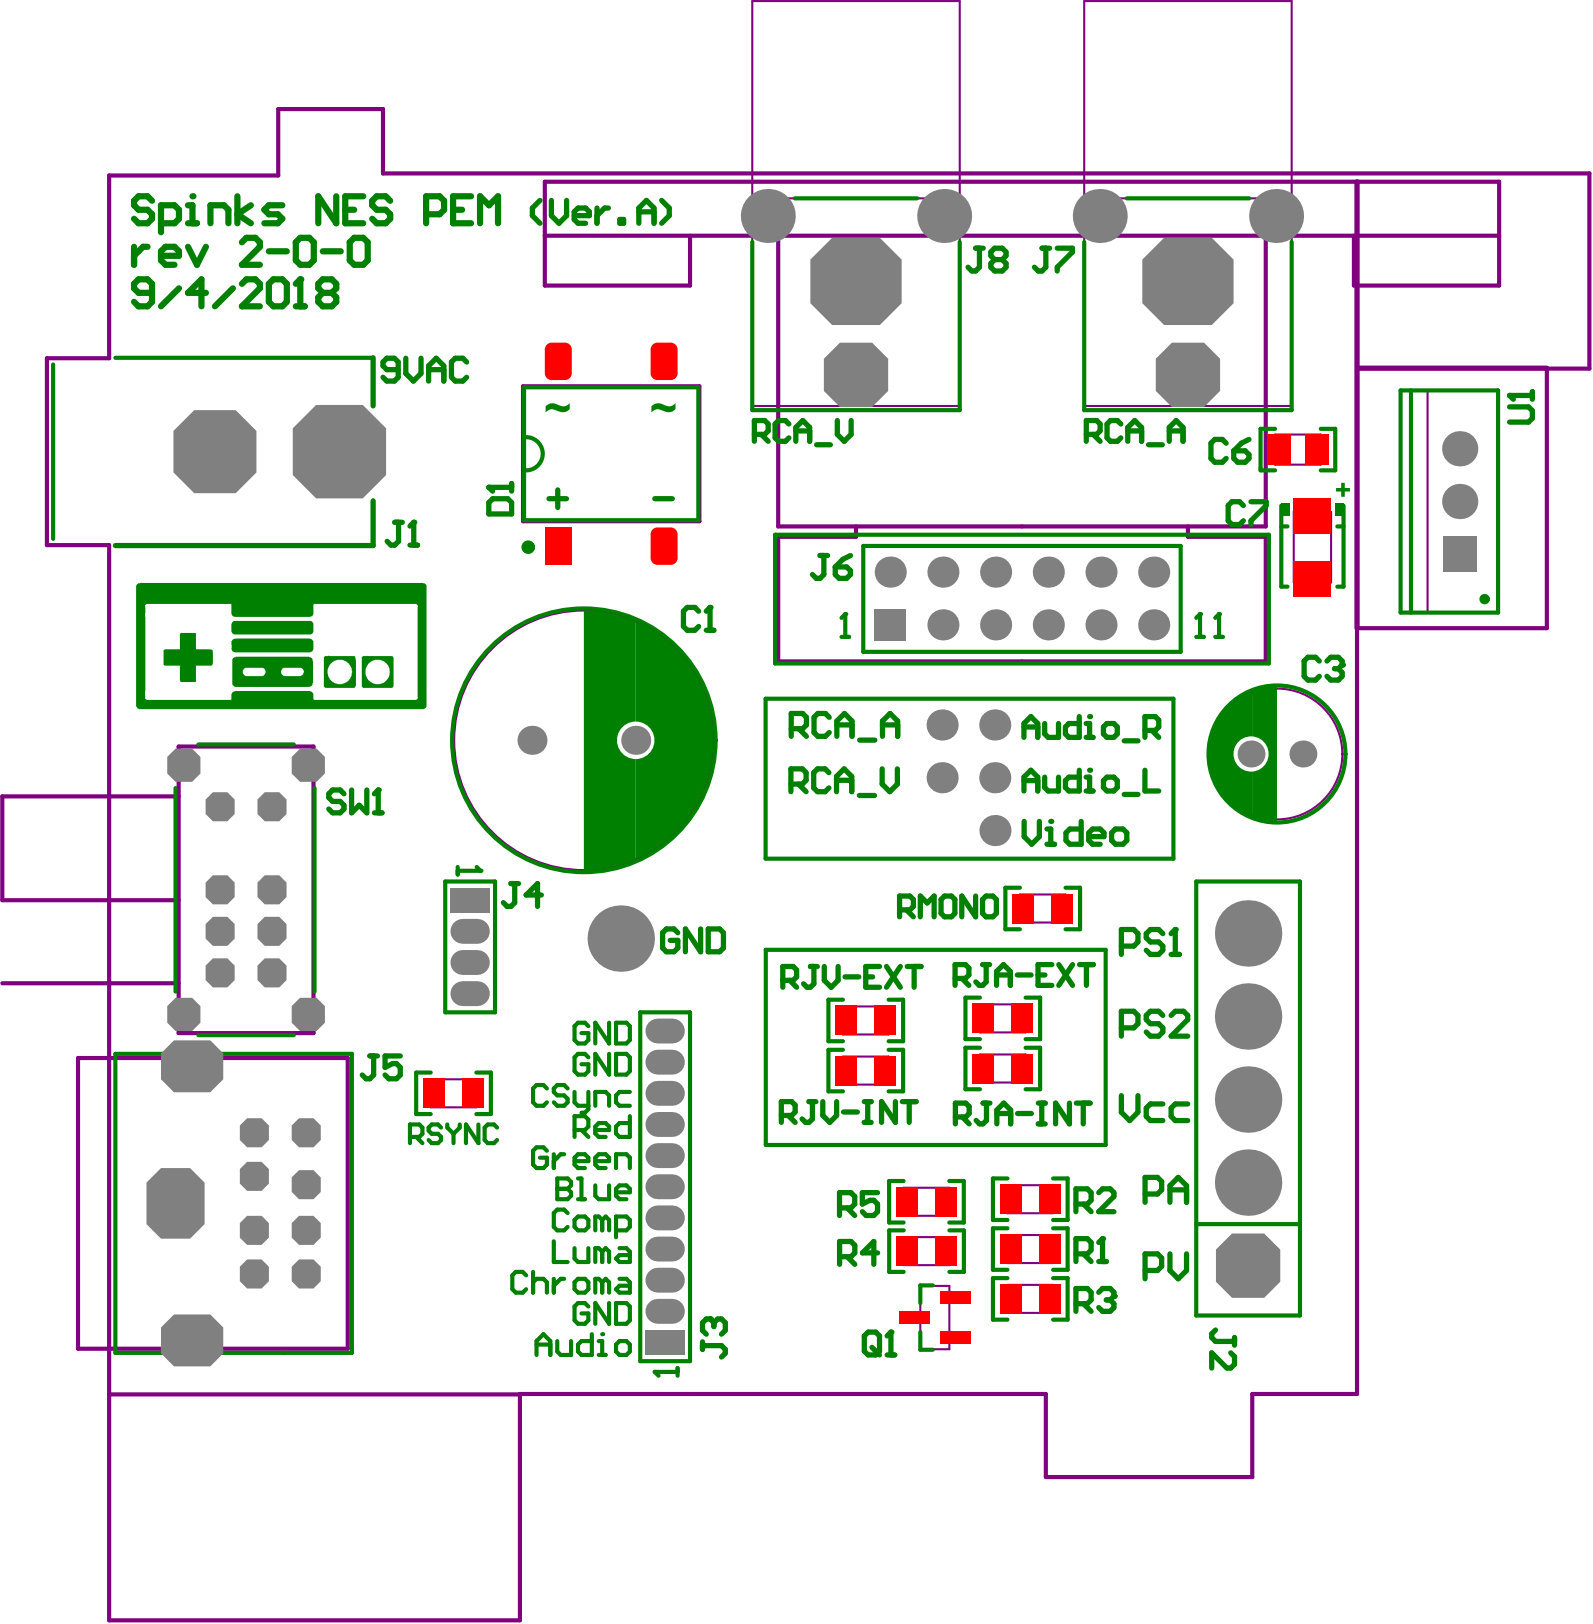
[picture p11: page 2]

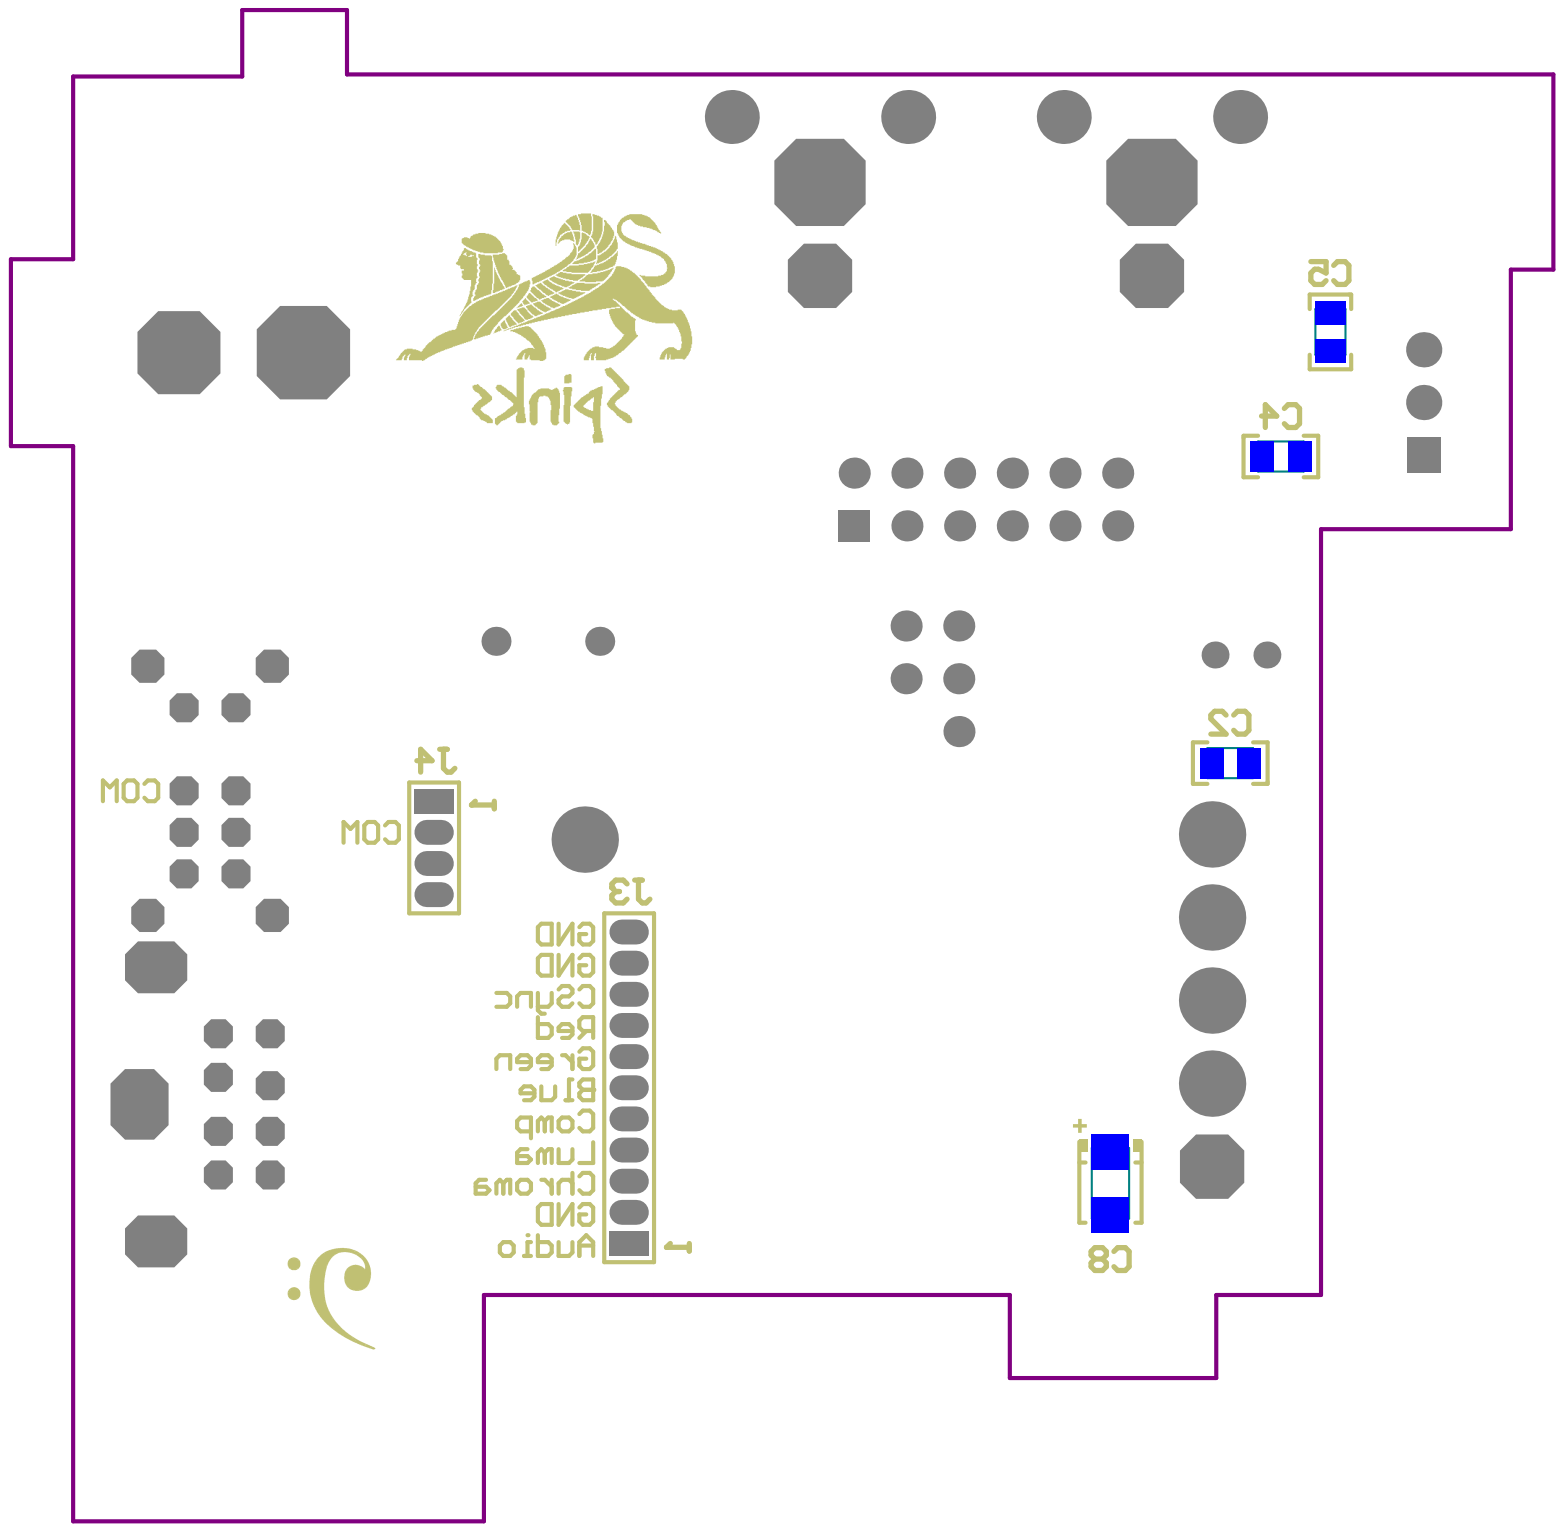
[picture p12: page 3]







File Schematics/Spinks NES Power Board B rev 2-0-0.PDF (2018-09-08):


Use this switch as the palette select
for NES with RGB mod.

Resistor jumpers RJV and RJAallow
you to use either the composite video
and audio from the NES motherboard,
or from an external source.

Some people like to perform
"stereo" mods to their NES.

If you wish to do so, leave
RJA_INT and RJA_EXT
unpopulated. Remove RMONO,
and supply your own stereo
audio wires into the breakout
area below.

THERE IS NO GROUND ON THE
MOTHERBOARD CONNECTOR.

YOU MUST INSTALL A WIRE FROM
ONE OF THE GROUNDS ON THIS
BOARD TO THE GROUND PLANE ON
THE MOTHERBOARD.

The original RF board used the metal box
as a ground.

Unless you are using RCAjacks,
don't worry about this section.

Green | Green 2
CSync | C-Sync/+12V 3
Blue | Blue 4

Install jumpers between the
AV breakout section and the
RCAjack breakout section to
use the RCAjacks. This will
let you route audio or video
anywhere you want.

Optional TTL to 75 ohm
compatibility jumper.

If needed, remove and
install a 470 ohm resistor
in its place.

NES Power Entry Module (Version B) Title

Size: Letter | Drawn By: M. Spinks | Revision: 2-0-0

Date: 9/4/2018 Time: 4:00:00 PM | | Sheet 1 of 1

Power Board Schematic Ver B.SchDoc
File:









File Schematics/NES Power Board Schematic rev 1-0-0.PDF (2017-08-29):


Use this switch as the palette select
for NES with RGB mod.

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

XRGB Mini DIN Connector

You can leave the case un-modified
and use the RCAjacks as composite
video and audio outputs. Or, you
can use one or both of these AV
connectors.

Green | | Green 7
Red | | Red 8

If you choose to use the simple
RCAmethod, you will need to
install jumpers wires from the AV
Breakout section to the RCAjacks

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

Green | Green 2
CSync | C-Sync/+12V 3
Blue | Blue 4

You will need to install jumpers
wires to these RCAJacks.

You could use the AV jacks like
normal, and leave the RF jack
unpopulated.

Or you could use the RF jack as a

If needed, cut trace and
install a 470 ohm
resistor.

NES Power Entry Board Title

Size: Letter | Drawn By: M. Spinks | Revision: 1-0-0

Date: 8/29/2017 Time: 9:20:08 AM | | Sheet 1 of 1








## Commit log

2017-08-25 First Commit
    Schematics, BOM, and Gerbers for rev 1-0-0 are done!
    [NES Power Board BOM rev 1-0-0.xls, NES Power Board.PrjPcb, Pick Place rev 1-0-0.csv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]
2017-08-29 Modified slide switch
    Changed slide switch to a DP3T for the palette selector. It was too
    difficult to find a SPDT On-Off-On switch that was the correct height.
    Also a DP3T switch was easier to find than a SP3T.
    [NES Power Board BOM rev 1-0-0.xls, NES Power Board BOM rev 1-0-0.xlsx, NES Power Board.PrjPcb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]
2017-09-13 rev 1-1-0
    Moved motherboard connector just a little. Made a little more space
    between edge of PCB and RCA mounting holes. Moved 5V regulator down just
    a bit. Moved capacitor out of the way of the heatsink.
    [NES Power Board BOM rev 1-0-0.xlsx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]
2018-09-08 Rev 2
    This version has two projects in it. One that has the mini-DIN
    connector, and one that does not. Once I get the board tested, I will
    generate the BOM.
    [NES Power Board Ver A.PrjPcb, NES Power Board Ver B.PrjPcb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]
2020-12-04 Rev 2-5-0 Ver A
    I'm only doing version A until I've fully tested everything. And I
    probably won't be able to test it for some time unfortunately.
    This is a two layer board. I separated the traces for the audio and
    video as best I could. This is fix issues with the noise channel causing
    little bits of static to appear on screen. This was only noticeable in
    Mega Man 2 with the black intro screen. But MM2 is one of my favorites,
    so that is unnacceptable. If this doesn't work, I may have to do a 4
    layer version.
    Fixed all plated through holes. I think Altium likes to guess what you
    are doing and set your default settings for you. I think what happened
    was I started making the mounting holes wh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
    [NES Power Board Ver A BOM.xls, NES Power Board Ver A.PrjPcb, Power Board Schematic Ver A.SchDoc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]
2020-12-04 Added via stitching in certain places
    [Power PCB Ver A.PcbDoc]
